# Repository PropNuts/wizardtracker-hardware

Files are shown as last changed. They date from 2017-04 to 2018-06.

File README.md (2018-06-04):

# STOP!

__This project has moved to GitLab:__ https://gitlab.com/PropNuts/wizardtracker-hardware

__There will be no further updates here.__

# wizardtracker-hardware

This project contains the hardware and firmware for the PropNuts WizardTracker,
an RSSI-based lap timer for drone racing.

## Hardware

The KiCad files can be found under `hardware/`.

<p align="center">
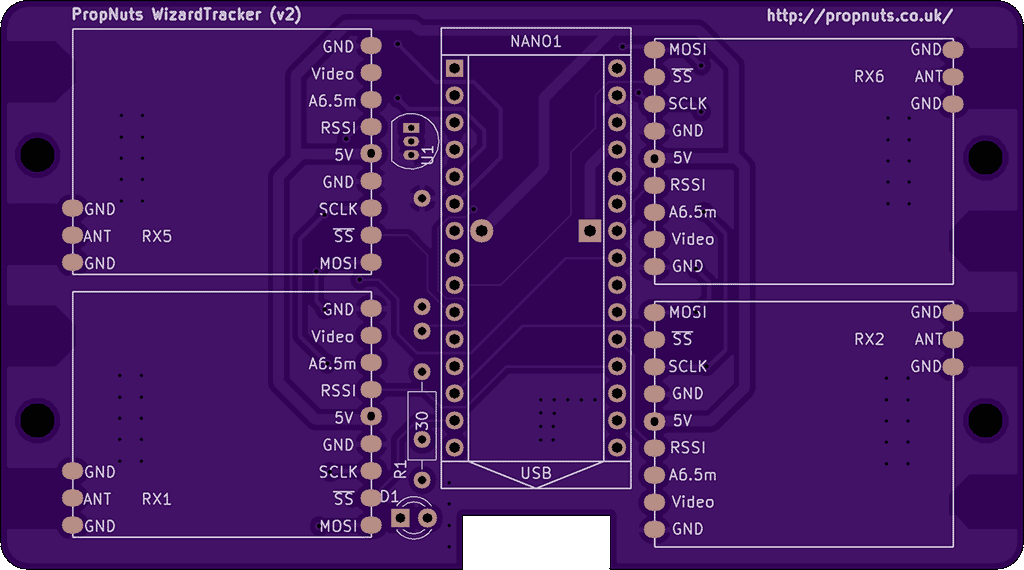
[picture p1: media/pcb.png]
  
</p>

The current revision (v2) allows for a total of either eight receivers, or six
receivers with voltage and temperature monitoring. A voltage regulator and XT60
are mounted onboard to provide power.

<p>
  <a href="https://oshpark.com/shared_projects/VPjVFjat">
    
  </a>
</p>

### Parts List

You can put together a full system for around ~£65.

- [RX5808s (6x or 8x)](https://www.banggood.com/FPV-5_8G-Wireless-Audio-Video-Receiving-Module-RX5808-p-84775.html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)
- [Arduino Nano](https://www.banggood.com/ATmega328P-Nano-V3-Controller-Board-Compatible-Arduino-p-940937.html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)
- [BEC (5V)](https://www.banggood.com/Diatone-Mini-2A-BEC-V2_0-Version-3_3V-5V-12V-For-RC-Multirotors-p-1032859.html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)
- [XT60](https://www.banggood.com/10X-XT60-Male-Female-Bullet-Connectors-Plugs-For-RC-Battery-p-958017.html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)
- [LM35](https://www.banggood.com/3Pcs-LM35DZ-TO-92-LM35-Precision-Centigrade-Temperature-Sensor-p-1091397.html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)
- [Resistors (1x 330, 1x 10k, 1x 100k)](https://www.banggood.com/Wholesale-Metal-Film-Resistor-Assorted-Kit-30-Kinds-Value-Total-600pcs-20pcs-Each-p-53320.html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)
- [LEDs](https://www.banggood.com/100pcs-3mm-LED-Light-emitting-Diode-5-Colors-Electronic-Component-Pack-p-1106574.html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)
- [Schottky Diode (1x 1N5817)](https://www.banggood.com/100-Pcs-030892-Diodes-Package-Rectifier-Schottky-8-Type-In-Component-Box-p-1164787.html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)
- [Pin Headers](https://www.banggood.com/10-Pcs-40-Pin-2_54mm-Single-Row-Male-Pin-Header-Strip-For-Arduino-p-918427.html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)

_These are affiliate links._

## Firmware

1. Grab the latest version of the Arduino IDE.
2. Clone the repository and open `firmware/firmware.ino`.
3. Edit `Config.h` to your needs.
4. Compile and flash the code.
5. Pray the magic smoke stays in.

### Protocol

On boot, the firmware opens serial at `250000bps`. After a short delay, it will
begin sending RSSI values for each module, seperated by a space, ending in a new
line. Each line is prefixd with `r `.

In calibrated output mode, values range between `0` to `255`. In raw output
mode (default), values range between `0` to  `1023`.

    < r 110 220 150 243 135 254
    < r 140 231 143 192 148 244
    ... etc

If enabled, voltage and temperature values will be sent periodically. Voltage
is prefixed with `v ` and temperature is prefixed with `t `.

    < v 16.08
    < t 56.33
    ... etc

#### Commands

The command parser is extremely niave, with little to no error checking. Expect
strange results with malformed commands. All command should end in a new line
character.

Frequencies can be set by sending `f <index> <frequency>`. These frequencies
will be saved and reloaded on startup.

    > f 0 5745
    < ok
    > f 1 5975
    < ok
    ... etc

Modules can be calibrated using `n` (minimum) and `m` (maximum). These
calibration values will be saved and reloaded on startup. The device must be
rebooted for calibration to take effect.

    [all modules set to same frequency]
    [transmitter powered down]
    > n
    < ok
    [transmitter powered up]
    > m
    < ok

Output can be toggled between raw output using `r`, and calibration output
using `s`. The default mode is raw output. This setting is saved and will be
reloaded on startup.

    > r
    < ok
    < r 395 345 299 405 514 445
    < ... etc
    > s
    < ok
    < r 0 5 8 1 10 13
    < ... etc

Information about the device can be requested using `?`. The device will respond
in the format `? <module count> <frequency 1>...<frequency n> <raw mode>`.

    > ?
    < ? 6 5695 5695 5695 5695 5695 5695 1
    [6 receivers all on 5695MHz, with raw mode enabled]
    < ok

## Acknowledgements

The source code for this project is based on [my rx5808-pro-diversity rewrite](https://github.com/Knifa/rx5808-pro-diversity/tree/tidy-up).

## License

This project is licensed under the terms of the MIT license.

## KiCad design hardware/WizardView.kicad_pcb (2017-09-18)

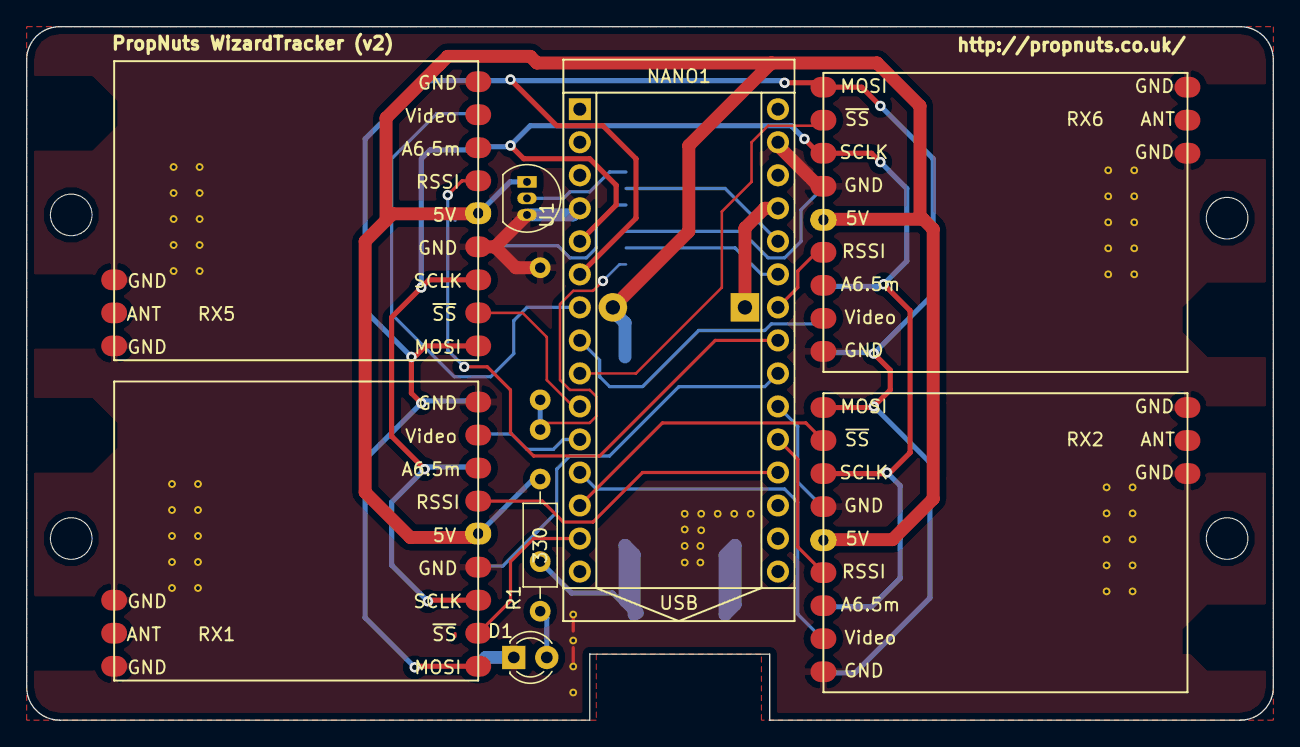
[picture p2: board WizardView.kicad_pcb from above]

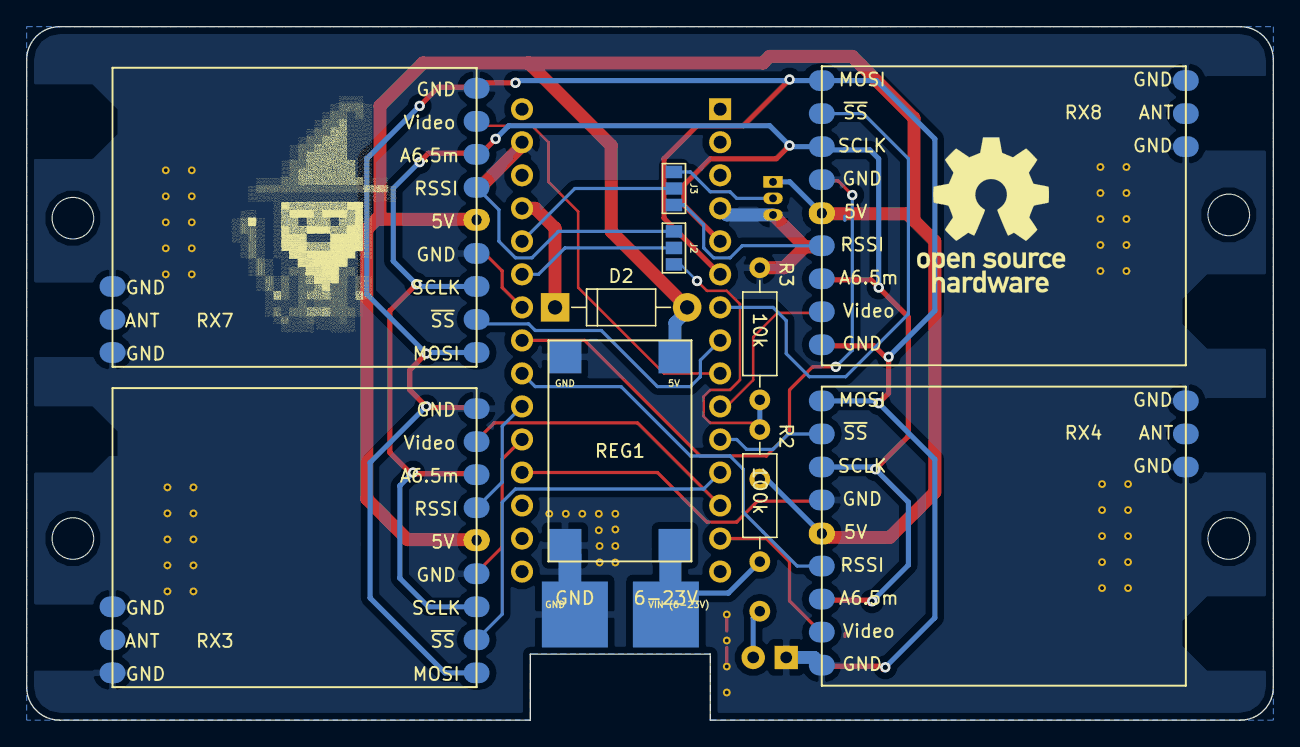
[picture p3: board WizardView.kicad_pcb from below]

Board: 2 copper layers, 95.9 x 53.3 mm, 19 parts (11 on the bottom side), 27 nets.

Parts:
D1: LED; LED_D3.0mm
D2: D_Schottky; D_DO-41_SOD81_P10.16mm_Horizontal
J1: CONN_01X02; XT60_5V
J2, J3: GS3
NANO1: ArduinoNano
R1: 330; R_Axial_DIN0207_L6.3mm_D2.5mm_P10.16mm_Horizontal
R2: 100k; R_Axial_DIN0207_L6.3mm_D2.5mm_P10.16mm_Horizontal
R3: 10k; R_Axial_DIN0207_L6.3mm_D2.5mm_P10.16mm_Horizontal
REG1: 5VRegulator; 5VBEC
RX1, RX2, RX3, RX4, RX5, RX6, RX7, RX8: RX5808
U1: LM35-LP; TO-92_Inline_Narrow_Oval

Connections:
+5V: D2.2, R1.1, REG1.3, RX1.5, RX2.5, RX3.5, RX4.5, RX5.5, RX6.5, RX7.5, RX8.5, U1.1
+BATT: J1.2, R2.1, REG1.1
/BATTDIV: J2.3, R2.2, R3.1
/MOSI: NANO1.6, RX1.9, RX2.9, RX3.9, RX4.9, RX5.9, RX6.9, RX7.9, RX8.9
/RSSI1: NANO1.27, RX1.4
/RSSI2: NANO1.26, RX2.4
/RSSI3: NANO1.25, RX3.4
/RSSI4: NANO1.24, RX4.4
/RSSI5: NANO1.23, RX5.4
/RSSI6: NANO1.22, RX6.4
/RSSI7: J2.1, RX7.4
/RSSI8: J3.1, RX8.4
/SCLK: NANO1.5, RX1.7, RX2.7, RX3.7, RX4.7, RX5.7, RX6.7, RX7.7, RX8.7
/TEMP: J3.3, U1.2
/~SS1: NANO1.14, RX1.8
/~SS2: NANO1.13, RX2.8
/~SS3: NANO1.12, RX3.8
/~SS4: NANO1.11, RX4.8
/~SS5: NANO1.10, RX5.8
/~SS6: NANO1.9, RX6.8
/~SS7: NANO1.8, RX7.8
/~SS8: NANO1.7, RX8.8
GND: D1.1, J1.1, NANO1.4, NANO1.17, R3.2, REG1.2, REG1.4, RX1.1, RX1.6, RX1.10, RX1.12, RX2.1, RX2.6, RX2.10, RX2.12, RX3.1, RX3.6, RX3.10, RX3.12, RX4.1, RX4.6, RX4.10, RX4.12, RX5.1, RX5.6, RX5.10, RX5.12, RX6.1, RX6.6, RX6.10, RX6.12, RX7.1, RX7.6, RX7.10, RX7.12, RX8.6, RX8.10, RX8.12, U1.3
unnamed: D1.2, R1.2
unnamed: D2.1, NANO1.19
unnamed: J2.2, NANO1.21
unnamed: J3.2, NANO1.20

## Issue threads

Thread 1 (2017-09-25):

Improve RSSI Rate

Knifa, 2017-09-25:
Disabling the serial delay timer gives ~1300Hz read rates (sub-millisecond accuracy). Need to double check the output is accurate, serial buffer is not causing issues, etc.

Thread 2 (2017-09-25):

KiCad complains about missing RX5808 library

Knifa, 2017-09-25:

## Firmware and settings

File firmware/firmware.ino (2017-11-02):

#include <stdint.h>
#include <avr/pgmspace.h>

#include "Config.h"

#include "EepromSettings.h"
#include "Receiver.h"
#include "Monitor.h"
#include "Timer.h"


#ifndef cbi
    #define cbi(sfr, bit) (_SFR_BYTE(sfr) &= ~_BV(bit))
#endif

#ifndef sbi
    #define sbi(sfr, bit) (_SFR_BYTE(sfr) |= _BV(bit))
#endif


Receiver receivers[RECEIVER_COUNT];

#ifdef TEMP_MONITORING_ENABLED
    Monitor tempMonitor(TEMP_MONITORING_PIN, TEMP_MONITORING_MULTIPLIER);
#endif

#ifdef VOLTAGE_MONITORING_ENABLED
    Monitor voltMonitor(VOLTAGE_MONITORING_PIN, VOLTAGE_MONITORING_MULTIPLIER);
#endif

Timer rssiTimer(RSSI_DELAY_MS);
#ifdef MONITORING_ENABLED
    Timer monitorTimer(MONITORING_DELAY_MS);
#endif


const char serialSeperator = ' ';
const char lineEnding = '\n';


void setup() {
    enableFastAdcRead();

    // Set pin defaults.
    pinMode(LED_PIN, OUTPUT);
    pinMode(RECEIVER_PIN_SPI_CLK, OUTPUT);
    pinMode(RECEIVER_PIN_SPI_DATA, OUTPUT);

    digitalWrite(RECEIVER_PIN_SPI_CLK, LOW);
    digitalWrite(RECEIVER_PIN_SPI_DATA, LOW);

    for (uint8_t i = 0; i < RECEIVER_COUNT; i++) {
        pinMode(RECEIVER_PIN_SPI_SS_START - i, OUTPUT);
        pinMode(RECEIVER_PIN_RSSI_START + i, INPUT);
        digitalWrite(RECEIVER_PIN_SPI_SS_START + i, HIGH);
    }

    #ifdef TEMP_MONITORING_ENABLED
        pinMode(TEMP_MONITORING_PIN, INPUT);
    #endif

    #ifdef VOLTAGE_MONITORING_ENABLED
        pinMode(VOLTAGE_MONITORING_PIN, INPUT);
    #endif

    EepromSettings.load();

    // Wait for modules to settle.
    delay(BOOT_DELAY_MS);

    // Configure receivers.
    for (uint8_t i = 0; i < RECEIVER_COUNT; i++) {
        receivers[i].init(
            RECEIVER_PIN_SPI_CLK,
            RECEIVER_PIN_SPI_DATA,
            RECEIVER_PIN_SPI_SS_START - i,
            RECEIVER_PIN_RSSI_START + i,
            EepromSettings.rssiMin[i],
            EepromSettings.rssiMax[i]
        );

        receivers[i].setFrequency(EepromSettings.frequency[i]);
    }

    rssiTimer.reset();
    #ifdef MONITORING_ENABLED
        monitorTimer.reset();
    #endif

    Serial.begin(SERIAL_BAUD);

    // Ready to go!
    digitalWrite(LED_PIN, HIGH);
}

void loop() {
    if (rssiTimer.hasTicked()) {
        for (uint8_t i = 0; i < RECEIVER_COUNT; i++) {
            receivers[i].updateRssi();
        }

        writeRssiData();
        rssiTimer.reset();
    }

    #ifdef MONITORING_ENABLED
        if (monitorTimer.hasTicked()) {
            #ifdef TEMP_MONITORING_ENABLED
                tempMonitor.update();
                writeTempMonitorData();
            #endif

            #ifdef VOLTAGE_MONITORING_ENABLED
                voltMonitor.update();
                writeVoltMonitorData();
            #endif

            monitorTimer.reset();
        }
    #endif

    parseCommands();
}


void writeRssiData() {
    Serial.print(F("r "));

    for (uint8_t i = 0; i < RECEIVER_COUNT; i++) {
        if (EepromSettings.rawMode)
            Serial.print(receivers[i].rssiRaw, DEC);
        else
            Serial.print(receivers[i].rssi, DEC);

        if (i < RECEIVER_COUNT - 1)
            Serial.print(serialSeperator);
    }

    Serial.print(lineEnding);
}

#ifdef TEMP_MONITORING_ENABLED
void writeTempMonitorData() {
    Serial.print(F("t "));
    Serial.print(tempMonitor.value, 2);
    Serial.print(lineEnding);
}
#endif

#ifdef VOLTAGE_MONITORING_ENABLED
void writeVoltMonitorData() {
    Serial.print(F("v "));
    Serial.print(voltMonitor.value, 2);
    Serial.print(lineEnding);
}
#endif

void parseCommands() {
    if (Serial.available() > 0) {
        const char command = Serial.read();

        switch (command) {
            // Status
            case '?': {
                Serial.print(F("? "));
                Serial.print(RECEIVER_COUNT, DEC);
                Serial.print(serialSeperator);

                for (uint8_t i = 0; i < RECEIVER_COUNT; i++) {
                    Serial.print(EepromSettings.frequency[i]);
                    Serial.print(serialSeperator);
                }

                Serial.print(EepromSettings.rawMode ? 1 : 0, DEC);
                Serial.print(lineEnding);
            } break;

            // Set frequency.
            case 'f': {
                uint8_t receiverIndex = Serial.parseInt();
                uint16_t frequency = Serial.parseInt();

                if (receiverIndex == 0 && frequency == 0)
                    break;

                if (receiverIndex < 0 || receiverIndex >= RECEIVER_COUNT)
                    break;

                receivers[receiverIndex].setFrequency(frequency);
                EepromSettings.frequency[receiverIndex] = frequency;
                EepromSettings.save();
            } break;

            // Calibrate minimum RSSI values.
            case 'n': {
                for (uint8_t i = 0; i < RECEIVER_COUNT; i++) {
                    EepromSettings.rssiMin[i] =
                        (uint16_t) receivers[i].rssiRaw;
                }

                EepromSettings.save();
            } break;

            // Calibrate maximum RSSI values.
            case 'm': {
                for (uint8_t i = 0; i < RECEIVER_COUNT; i++) {
                    EepromSettings.rssiMax[i] =
                        (uint16_t) receivers[i].rssiRaw;
                }

                EepromSettings.save();
            } break;

            // Enable raw mode.
            case 'r': {
                EepromSettings.rawMode = true;
                EepromSettings.save();
            } break;

            // Disable raw mode.
            case 's': {
                EepromSettings.rawMode = false;
                EepromSettings.save();
            } break;
        }

        Serial.find('\n');
        Serial.print(F("ok"));
        Serial.print(lineEnding);
    }
}

void enableFastAdcRead() {
    sbi(ADCSRA, ADPS2);
    cbi(ADCSRA, ADPS1);
    cbi(ADCSRA, ADPS0);
}

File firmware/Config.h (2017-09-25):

#ifndef CONFIG_H
#define CONFIG_H


// Receivers
// ==============

// Number of receivers on the board. Make sure these are sequentially connected
// to the pins --- no gaps!
#define RECEIVER_COUNT 6

#define RECEIVER_PIN_SPI_CLK 2
#define RECEIVER_PIN_SPI_DATA 3
#define RECEIVER_PIN_SPI_SS_START 11
#define RECEIVER_PIN_RSSI_START A0


// Temperature Monitoring
// ======================
#define TEMP_MONITORING_ENABLED

#ifdef TEMP_MONITORING_ENABLED
    #define TEMP_MONITORING_PIN A7

    // Multiplier for raw ADC value to get to celcius. Defaults work for the
    // LM35  at 0.01V/C.
    #define TEMP_MONITORING_MULTIPLIER (((1.0f / 1024.0f) * 5.0f) / 0.01f)
#endif


// Voltage Monitoring
// ==================
#define VOLTAGE_MONITORING_ENABLED

#ifdef VOLTAGE_MONITORING_ENABLED
    #define VOLTAGE_MONITORING_PIN A6

    // Multiplier for raw ADC value to get to volts. Defaults work for a 1:11
    // divider.
    #define VOLTAGE_MONITORING_MULTIPLIER (1.0f / 1024.0f * 5.0f * 11.0f)
#endif


// Serial
// ====

#define SERIAL_BAUD 250000

// Delay between RSSI messages. Too fast and the buffer clogs and things get
// weird. 2ms is a good default value.
#define RSSI_DELAY_MS 2

// Delay between monitoring messages.
#define MONITORING_DELAY_MS 10000


// Misc
// ====

// Delay to wait for modules to settle, etc.
#define BOOT_DELAY_MS 1000


// =============================================================================


#define LED_PIN 13

#if defined(VOLTAGE_MONITORING_ENABLED) || defined(TEMP_MONITORING_ENABLED)
    #define MONITORING_ENABLED
#endif


#endif

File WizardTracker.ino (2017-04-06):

#include <stdint.h>
#include "receiver.h"


#define PIN_LED 13
#define PIN_SPI_CLK 2
#define PIN_SPI_DATA 3
#define PIN_SPI_SS_RX1 4
#define PIN_SPI_SS_RX2 5
#define PIN_SPI_SS_RX3 6
#define PIN_SPI_SS_RX4 7

#define PIN_RSSI_RX1 A0
#define PIN_RSSI_RX2 A1
#define PIN_RSSI_RX3 A2
#define PIN_RSSI_RX4 A3

#define SERIAL_DELAY 10


Receiver rx1 = Receiver(
    PIN_SPI_CLK,
    PIN_SPI_DATA,
    PIN_SPI_SS_RX1,
    PIN_RSSI_RX1
);

Receiver rx2 = Receiver(
    PIN_SPI_CLK,
    PIN_SPI_DATA,
    PIN_SPI_SS_RX2,
    PIN_RSSI_RX2
);

Receiver rx3 = Receiver(
    PIN_SPI_CLK,
    PIN_SPI_DATA,
    PIN_SPI_SS_RX3,
    PIN_RSSI_RX3
);

Receiver rx4 = Receiver(
    PIN_SPI_CLK,
    PIN_SPI_DATA,
    PIN_SPI_SS_RX4,
    PIN_RSSI_RX4
);


void setup() {
    // Set pin defaults.
    pinMode(PIN_LED, OUTPUT);
    pinMode(PIN_SPI_CLK, OUTPUT);
    pinMode(PIN_SPI_DATA, OUTPUT);
    pinMode(PIN_SPI_SS_RX1, OUTPUT);
    pinMode(PIN_SPI_SS_RX2, OUTPUT);
    pinMode(PIN_SPI_SS_RX3, OUTPUT);
    pinMode(PIN_SPI_SS_RX4, OUTPUT);
    pinMode(PIN_RSSI_RX1, INPUT);
    pinMode(PIN_RSSI_RX2, INPUT);
    pinMode(PIN_RSSI_RX3, INPUT);
    pinMode(PIN_RSSI_RX4, INPUT);

    digitalWrite(PIN_SPI_CLK, LOW);
    digitalWrite(PIN_SPI_DATA, LOW);
    digitalWrite(PIN_SPI_SS_RX1, HIGH);
    digitalWrite(PIN_SPI_SS_RX2, HIGH);
    digitalWrite(PIN_SPI_SS_RX3, HIGH);
    digitalWrite(PIN_SPI_SS_RX4, HIGH);

    // Set to race frequencies.
    delay(1000); // Wait for modules to settle.
    rx1.setFrequency(5665);
    rx2.setFrequency(5745);
    rx3.setFrequency(5885);
    rx4.setFrequency(5945);

    Serial.begin(115200);

    // Show that we're ready and on.
    digitalWrite(PIN_LED, HIGH);
}

void loop() {
    rx1.updateRssi();
    rx2.updateRssi();
    rx3.updateRssi();
    rx4.updateRssi();

    writeSerialData();
}


void writeSerialData() {
    static uint32_t nextSerialWrite = 0;
    if (millis() < nextSerialWrite)
        return;

    static const char seperator = '\t';

    Serial.print(rx1.rssi, DEC);
    Serial.print(seperator);
    Serial.print(rx2.rssi, DEC);
    Serial.print(seperator);
    Serial.print(rx3.rssi, DEC);
    Serial.print(seperator);
    Serial.print(rx4.rssi, DEC);
    Serial.println();

    nextSerialWrite = millis() + SERIAL_DELAY;
}

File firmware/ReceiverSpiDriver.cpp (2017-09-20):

#include <Arduino.h>
#include <stdint.h>

#include "ReceiverSpiDriver.h"


#define SPI_ADDRESS_SYNTH_B 0x01


void ReceiverSpiDriver::init(
    uint8_t spiClockPin,
    uint8_t spiDataPin,
    uint8_t spiSelectPin
) {
    this->spiClockPin = spiClockPin;
    this->spiDataPin = spiDataPin;
    this->spiSelectPin = spiSelectPin;
}

void ReceiverSpiDriver::setSynthRegisterB(uint32_t data) {
    this->sendRegister(SPI_ADDRESS_SYNTH_B, data);
}


void ReceiverSpiDriver::sendRegister(uint8_t address, uint32_t data) {
    this->sendSlaveSelect(LOW);

    this->sendBits(address, 4);
    this->sendBit(HIGH); // Enable write.

    this->sendBits(data, 20);

    // Finished clocking data in
    this->sendSlaveSelect(HIGH);
    digitalWrite(this->spiClockPin, LOW);
    digitalWrite(this->spiDataPin, LOW);
    delayMicroseconds(1);
}

void ReceiverSpiDriver::sendBits(uint32_t bits, uint8_t count) {
    for (uint8_t i = 0; i < count; i++) {
        this->sendBit(bits & 0x1);
        bits >>= 1;
    }
}

void ReceiverSpiDriver::sendBit(uint8_t value) {
    digitalWrite(this->spiClockPin, LOW);
    delayMicroseconds(1);

    digitalWrite(this->spiDataPin, value);
    delayMicroseconds(1);
    digitalWrite(this->spiClockPin, HIGH);
    delayMicroseconds(1);

    digitalWrite(this->spiClockPin, LOW);
    delayMicroseconds(1);
}

void ReceiverSpiDriver::sendSlaveSelect(uint8_t value) {
    digitalWrite(this->spiSelectPin, value);
    delayMicroseconds(1);
}

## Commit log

2017-03-04 Fix function name typo for synth reg
    [receiver_driver.cpp]
2017-03-06 Attempt at fixing multiple device select
    [receiver_driver.cpp]
2017-03-06 Add some delays between setting channels + flash LED
2017-03-09 General tidy up, fixes, and RSSI out over serial
    [receiver_spi_driver.cpp]
2017-03-31 Add stub KiCad hardware design
    [WizardView.kicad_pcb, WizardView.sch]
2017-09-18 Update KiCad PCB to latest revision.
    [WizardView-B.Cu.gbl, WizardView-B.Mask.gbs, WizardView-B.SilkS.gbo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]
2017-09-20 Add PCB to README.md
2017-09-21 Implement volt/temp monitoring + configuration
2017-09-21 Add calibration.
2017-09-25 Add command for returning device information
2017-09-25 Fix boot settle happening after trying to configure the modules.
    [firmware.ino]
2017-09-25 Use prescaler ADC magic to make analog reads faster.
2017-10-11 Round voltage/temp to 2 decimal places
